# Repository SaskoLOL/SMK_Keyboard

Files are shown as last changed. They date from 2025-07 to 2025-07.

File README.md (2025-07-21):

# SMK_Keyboard
This is a cool 119 key mechanical keyboard. It has 9 macro keys, 4 on top and 5 on the left. (Total time spent: 40h)

#CAD
I modeled everything in fusion 360



This is the full case



It consist of 2 parts:



PCB
The schmetick consists of 119 switches and diodes and uses a rasbarry pi pico (orpheus pico)





The PCB consists only of 2 layers:



UPDATED PICTURE (because I had the thing mirrored and it looked like the screw holes would go trough the pcb and top case)



UPDATE: made the usb space look alot better:



Firmware:
The firmware was made in VS code with Pyhton

BOM:

119 cherry mx switches cost: 52.80€ Required: Yes Link: https://www.reichelt.at/at/de/shop/produkt/cherry_mx_blue_-_tastenmodul_-_fixierzapfen-369269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 

One orpheus pico: 10€ Required: No

M3x16mm screws (6x): 3€: Required: No

119 blank keycaps: 29,90 €: Required: Yes Link:https://www.caseking.de/ducky-blank-white-pbt-set-mda-profile-133-keycaps-ansi-us-layout-ansi-us-layout/GAKC-530.html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 ALIEXPRESS LINK (updated): https://de.aliexpress.com/i/1005008530984427.html?gatewayAdapt=glo2deu Cost:21,07$

3d printing Filament: 20€ Required Yes

Pcb: / Required: Yes
Total cost: 130$

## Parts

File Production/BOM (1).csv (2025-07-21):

Part | Amount | Cost | Link
Neodymium Magnet | 5x2mm | 7 | 7€ | https://amzn.eu/d/3slAySB
Rubber Pad | 10mm | 2 | 4€ | https://amzn.eu/d/7RgwESr
M2.5x10 screw | 7 | 11€ | https://amzn.eu/d/3ODUxXx
Cherry MX switches | 92 | 75€ | https://shop.cherry.de/mx-rgb-black-switch-kit.html
Keycaps | 92 | 25€ | https://amzn.eu/d/aOeOemJ
PCB | 1 | 50€ | jlcpcb.com
RPI Pico | 1 | 17€ | https://amzn.eu/d/3SUL29R
Filament/3d printed case | 1 | 24€ | https://amzn.eu/d/eSc6kCR

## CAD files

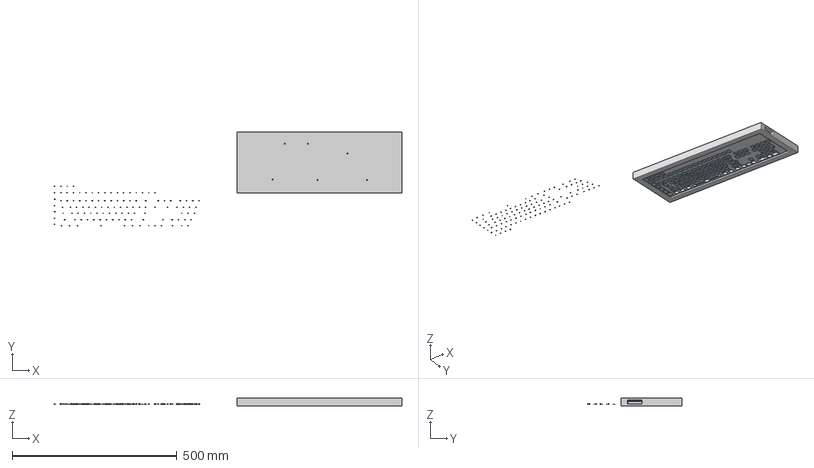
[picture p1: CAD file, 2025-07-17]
Production/wholeKeyboard (1).step
1056.0 x 286.5 x 23.0 mm
Case1
D_SOD-123 x 114
modern-keyboard-template_PCB
f97630a2094c01f0b01be9395de512cac0e4625c_switch

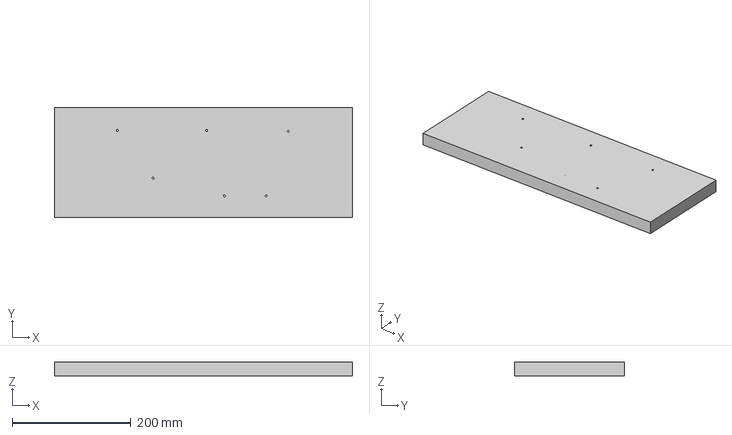
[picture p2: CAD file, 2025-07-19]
Production/Case v3 (1).step
501.0 x 185.0 x 23.0 mm

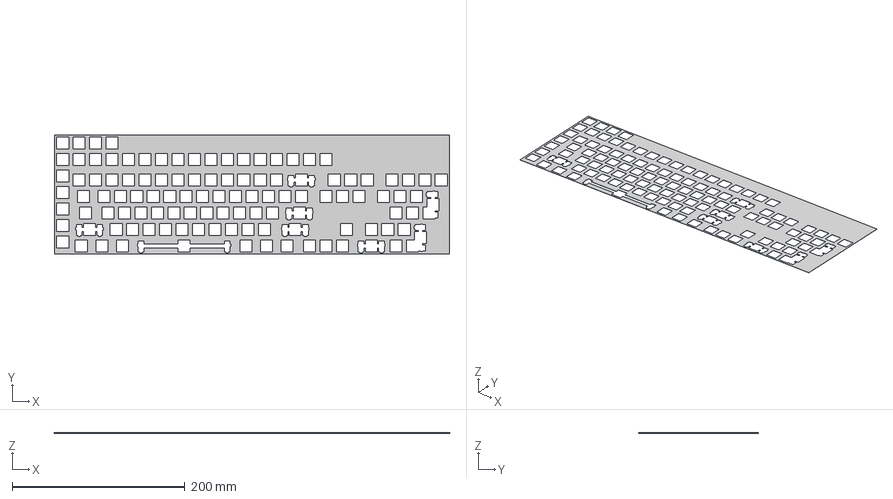
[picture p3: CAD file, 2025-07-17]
Production/topkey (1).step
457.2 x 138.1 x 0.2 mm

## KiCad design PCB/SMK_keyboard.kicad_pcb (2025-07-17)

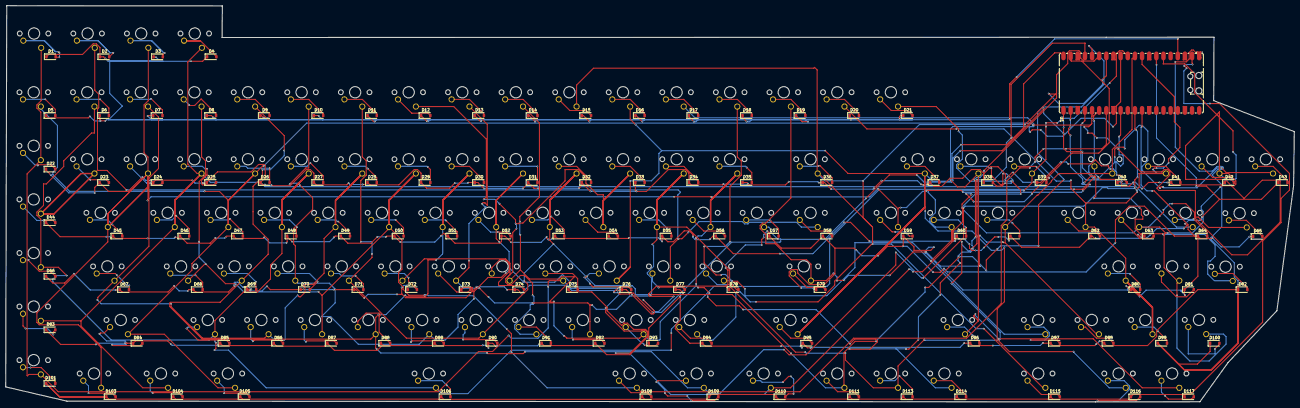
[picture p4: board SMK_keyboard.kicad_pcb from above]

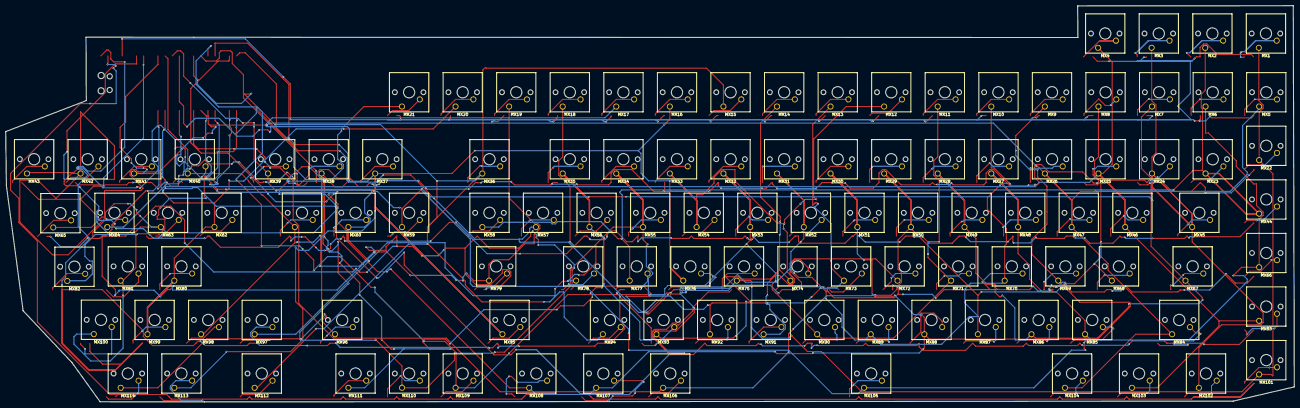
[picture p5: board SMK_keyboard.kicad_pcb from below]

Board: 2 copper layers, 458.2 x 140.9 mm, 229 parts (114 on the bottom side), 141 nets.

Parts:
D1, D2, D3, D4, D5, D6, D7, D8, D9, D10, D11, D12, D13, D14, D15, D16, D17, D18, D19, D20, D21, D22, D23, D24, D25, D26, D27, D28, D29, D30, D31, D32, D33, D34, D35, D36, D37, D38, D39, D40, D41, D42, D43, D44, D45, D46, D47, D48, D49, D50, D51, D52, D53, D54, D55, D56, D57, D58, D59, D60, D61, D62, D63, D64, D65, D66, D67, D68, D69, D70, D71, D72, D73, D74, D75, D76, D77, D78, D79, D80, D81, D82, D83, D84, D85, D86, D87, D88, D89, D90, D91, D92, D93, D94, D95, D96, D97, D98, D99, D100, D101, D103, D104, D105, D106, D108, D109, D110, D111, D113, D114, D115, D116, D117: D; D_SOD-123
MX1, MX2, MX3, MX4, MX5, MX6, MX7, MX8, MX9, MX10, MX11, MX12, MX13, MX14, MX15, MX16, MX17, MX18, MX19, MX20, MX21, MX22, MX23, MX24, MX25, MX26, MX27, MX28, MX29, MX30, MX31, MX32, MX33, MX34, MX35, MX36, MX37, MX38, MX39, MX40, MX41, MX42, MX43, MX44, MX45, MX46, MX47, MX48, MX49, MX50, MX51, MX52, MX53, MX54, MX55, MX56, MX57, MX58, MX59, MX60, MX61, MX62, MX63, MX64, MX65, MX66, MX67, MX68, MX69, MX70, MX71, MX72, MX73, MX74, MX75, MX76, MX77, MX78, MX79, MX80, MX81, MX82, MX83, MX84, MX85, MX86, MX87, MX88, MX89, MX90, MX91, MX92, MX93, MX94, MX95, MX96, MX97, MX98, MX99, MX100, MX101, MX102, MX103, MX104, MX105, MX106, MX107, MX108, MX109, MX110, MX111, MX112, MX113, MX114: MX_SW_HS; SW_Cherry_MX_1.00u_PCB
U1: Pico; RaspberryPi_Pico_Common_SMD

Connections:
unnamed: D1.2 (A), MX1.2
unnamed: D2.2 (A), MX2.2
unnamed: D3.2 (A), MX3.2
unnamed: D4.2 (A), MX4.2
unnamed: D5.2 (A), MX5.2
unnamed: D6.2 (A), MX6.2
unnamed: D7.2 (A), MX7.2
unnamed: D8.2 (A), MX8.2
unnamed: D9.2 (A), MX9.2
unnamed: D10.2 (A), MX10.2
unnamed: D11.2 (A), MX11.2
unnamed: D12.2 (A), MX12.2
unnamed: D13.2 (A), MX13.2
unnamed: D14.2 (A), MX14.2
unnamed: D15.2 (A), MX15.2
unnamed: D16.2 (A), MX16.2
unnamed: D17.2 (A), MX17.2
unnamed: D18.2 (A), MX18.2
unnamed: D19.2 (A), MX19.2
unnamed: D20.2 (A), MX20.2
unnamed: D21.2 (A), MX21.2
unnamed: D22.2 (A), MX22.2
unnamed: D23.2 (A), MX23.2
unnamed: D24.2 (A), MX24.2
unnamed: D25.2 (A), MX25.2
unnamed: D26.2 (A), MX26.2
unnamed: D27.2 (A), MX27.2
unnamed: D28.2 (A), MX28.2
unnamed: D29.2 (A), MX29.2
unnamed: D30.2 (A), MX30.2
unnamed: D31.2 (A), MX31.2
unnamed: D32.2 (A), MX32.2
unnamed: D33.2 (A), MX33.2
unnamed: D34.2 (A), MX34.2
unnamed: D35.2 (A), MX35.2
unnamed: D36.2 (A), MX36.2
unnamed: D37.2 (A), MX37.2
unnamed: D38.2 (A), MX38.2
unnamed: D39.2 (A), MX39.2
unnamed: D40.2 (A), MX40.2
unnamed: D41.2 (A), MX41.2
unnamed: D42.2 (A), MX42.2
unnamed: D43.2 (A), MX43.2
unnamed: D44.2 (A), MX44.2
unnamed: D45.2 (A), MX45.2
unnamed: D46.2 (A), MX46.2
unnamed: D47.2 (A), MX47.2
unnamed: D48.2 (A), MX48.2
unnamed: D49.2 (A), MX49.2
unnamed: D50.2 (A), MX50.2
unnamed: D51.2 (A), MX51.2
unnamed: D52.2 (A), MX52.2
unnamed: D53.2 (A), MX53.2
unnamed: D54.2 (A), MX54.2
unnamed: D55.2 (A), MX55.2
unnamed: D56.2 (A), MX56.2
unnamed: D57.2 (A), MX57.2
unnamed: D58.2 (A), MX58.2
unnamed: D59.2 (A), MX59.2
unnamed: D60.2 (A), MX60.2
unnamed: D61.2 (A), MX61.2
unnamed: D62.2 (A), MX62.2
unnamed: D63.2 (A), MX63.2
unnamed: D64.2 (A), MX64.2
unnamed: D65.2 (A), MX65.2
unnamed: D66.2 (A), MX66.2
unnamed: D67.2 (A), MX67.2
unnamed: D68.2 (A), MX68.2
unnamed: D69.2 (A), MX69.2
unnamed: D70.2 (A), MX70.2
unnamed: D71.2 (A), MX71.2
unnamed: D72.2 (A), MX72.2
unnamed: D73.2 (A), MX73.2
unnamed: D74.2 (A), MX74.2
unnamed: D75.2 (A), MX75.2
unnamed: D76.2 (A), MX76.2
unnamed: D77.2 (A), MX77.2
unnamed: D78.2 (A), MX78.2
unnamed: D79.2 (A), MX79.2
unnamed: D80.2 (A), MX80.2
unnamed: D81.2 (A), MX81.2
unnamed: D82.2 (A), MX82.2
unnamed: D83.2 (A), MX83.2
unnamed: D84.2 (A), MX84.2
unnamed: D85.2 (A), MX85.2
unnamed: D86.2 (A), MX86.2
unnamed: D87.2 (A), MX87.2
unnamed: D88.2 (A), MX88.2
unnamed: D89.2 (A), MX89.2
unnamed: D90.2 (A), MX90.2
unnamed: D91.2 (A), MX91.2
unnamed: D92.2 (A), MX92.2
unnamed: D93.2 (A), MX93.2
unnamed: D94.2 (A), MX94.2
unnamed: D95.2 (A), MX95.2
unnamed: D96.2 (A), MX96.2
unnamed: D97.2 (A), MX97.2
unnamed: D98.2 (A), MX98.2
unnamed: D99.2 (A), MX99.2
unnamed: D100.2 (A), MX100.2
unnamed: D101.2 (A), MX101.2
unnamed: D103.2 (A), MX102.2
unnamed: D104.2 (A), MX103.2
unnamed: D105.2 (A), MX104.2
unnamed: D106.2 (A), MX105.2
unnamed: D108.2 (A), MX106.2
unnamed: D109.2 (A), MX107.2
unnamed: D110.2 (A), MX108.2
unnamed: D111.2 (A), MX109.2
unnamed: D113.2 (A), MX110.2
unnamed: D114.2 (A), MX111.2
unnamed: D115.2 (A), MX112.2
unnamed: D116.2 (A), MX113.2
unnamed: D117.2 (A), MX114.2
unnamed: MX2.1, MX23.1, MX44.1, MX58.1, MX77.1
unnamed: MX12.1, MX33.1, MX54.1, MX72.1, MX91.1
unnamed: MX7.1, MX28.1, MX49.1, MX67.1, MX86.1
Row1: D75.1 (K), D77.1 (K), D82.1 (K), D83.1 (K), D84.1 (K), D85.1 (K), D86.1 (K), D87.1 (K), D88.1 (K), D89.1 (K), D90.1 (K), D91.1 (K), D92.1 (K), D93.1 (K), D94.1 (K), D95.1 (K), D96.1 (K), D97.1 (K), D98.1 (K), D99.1 (K), D100.1 (K), U1.1 (GPIO0)
Row2: D101.1 (K), D103.1 (K), D104.1 (K), D105.1 (K), D106.1 (K), D108.1 (K), D109.1 (K), D110.1 (K), D111.1 (K), D113.1 (K), D114.1 (K), D115.1 (K), D116.1 (K), D117.1 (K), U1.2 (GPIO1)
Row3: D1.1 (K), D2.1 (K), D3.1 (K), D4.1 (K), D5.1 (K), D6.1 (K), D7.1 (K), D8.1 (K), D9.1 (K), D10.1 (K), D11.1 (K), D12.1 (K), D13.1 (K), D14.1 (K), D15.1 (K), D16.1 (K), D17.1 (K), D18.1 (K), D19.1 (K), D20.1 (K), D21.1 (K), U1.4 (GPIO2)
Row4: D22.1 (K), D23.1 (K), D24.1 (K), D25.1 (K), D26.1 (K), D27.1 (K), D28.1 (K), D29.1 (K), D30.1 (K), D31.1 (K), D32.1 (K), D33.1 (K), D34.1 (K), D35.1 (K), D36.1 (K), D37.1 (K), D38.1 (K), D39.1 (K), D40.1 (K), D41.1 (K), D42.1 (K), U1.29 (GPIO22)
Row5: D43.1 (K), D44.1 (K), D45.1 (K), D46.1 (K), D47.1 (K), D48.1 (K), D49.1 (K), D50.1 (K), D51.1 (K), D52.1 (K), D53.1 (K), D54.1 (K), D55.1 (K), D56.1 (K), D60.1 (K), D61.1 (K), D62.1 (K), D63.1 (K), U1.7 (GPIO5)
Row6: D57.1 (K), D58.1 (K), D59.1 (K), D64.1 (K), D65.1 (K), D66.1 (K), D67.1 (K), D68.1 (K), D69.1 (K), D70.1 (K), D71.1 (K), D72.1 (K), D73.1 (K), D74.1 (K), D76.1 (K), D78.1 (K), D79.1 (K), D80.1 (K), D81.1 (K), U1.32 (GPIO27_ADC1)
col0: MX1.1, MX22.1, MX43.1, MX57.1, MX75.1, MX101.1, U1.21 (GPIO16)
col1: MX3.1, MX24.1, MX45.1, MX59.1, MX82.1, MX102.1, U1.22 (GPIO17)
col2: MX4.1, MX25.1, MX46.1, MX64.1, MX83.1, MX103.1, U1.24 (GPIO18)
col3: MX5.1, MX26.1, MX47.1, MX65.1, MX84.1, MX104.1, U1.25 (GPIO19)
col4: MX6.1, MX27.1, MX48.1, MX66.1, MX85.1, MX105.1, U1.26 (GPIO20)
col5: MX8.1, MX29.1, MX50.1, MX68.1, MX87.1, MX106.1, U1.27 (GPIO21)
col6: MX9.1, MX30.1, MX51.1, MX69.1, MX88.1, MX107.1, U1.31 (GPIO26_ADC0)
col7: MX10.1, MX31.1, MX52.1, MX70.1, MX89.1, MX108.1, U1.19 (GPIO14)
col8: MX11.1, MX32.1, MX53.1, MX71.1, MX90.1, MX109.1, U1.16 (GPIO12)
col9: MX13.1, MX34.1, MX55.1, MX73.1, MX92.1, MX110.1, U1.17 (GPIO13)
col10: MX14.1, MX35.1, MX56.1, MX74.1, MX93.1, MX111.1, U1.15 (GPIO11)
col11: MX15.1, MX36.1, MX94.1, MX112.1, U1.14 (GPIO10)
col12: MX16.1, MX37.1, MX76.1, MX95.1, MX113.1, U1.20 (GPIO15)
col13: MX17.1, MX38.1, MX96.1, MX114.1, U1.12 (GPIO9)
col14: MX18.1, MX39.1, MX60.1, MX78.1, MX97.1, U1.11 (GPIO8)
col15: MX19.1, MX40.1, MX61.1, MX79.1, MX98.1, U1.10 (GPIO7)
col16: MX20.1, MX41.1, MX62.1, MX80.1, MX99.1, U1.9 (GPIO6)
col17: MX21.1, MX42.1, MX63.1, MX81.1, MX100.1, U1.6 (GPIO4)

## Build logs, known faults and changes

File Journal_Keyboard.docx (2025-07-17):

Journel by Alexander Kulka for a mechanical Keyboard:

First Session, June 28

So I designed the schematic with the switches diodes and sorted them by rows and collums

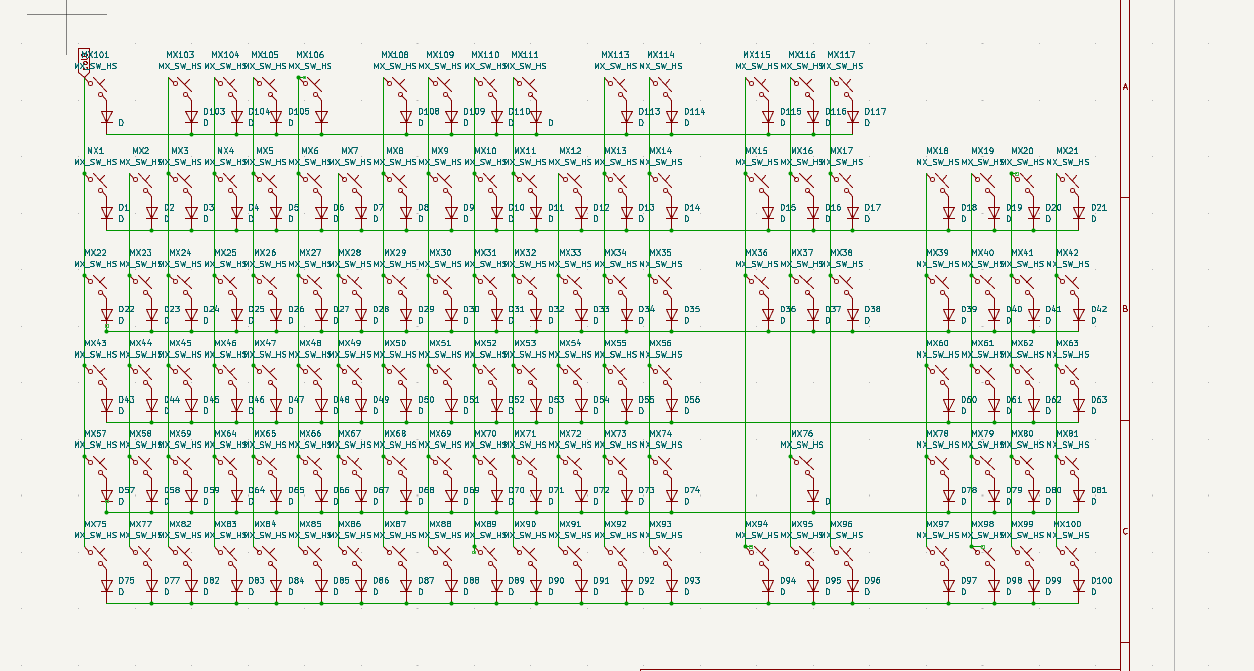
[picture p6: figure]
Obrázok, na ktorom je text, diagram, číslo, písmo Obsah vygenerovaný pomocou AI môže byť nesprávny.

I designed this with the help of a tutorial where he build a keyboard from scratch, in this session I also made the keyboard layout in keyboard layout edititor:

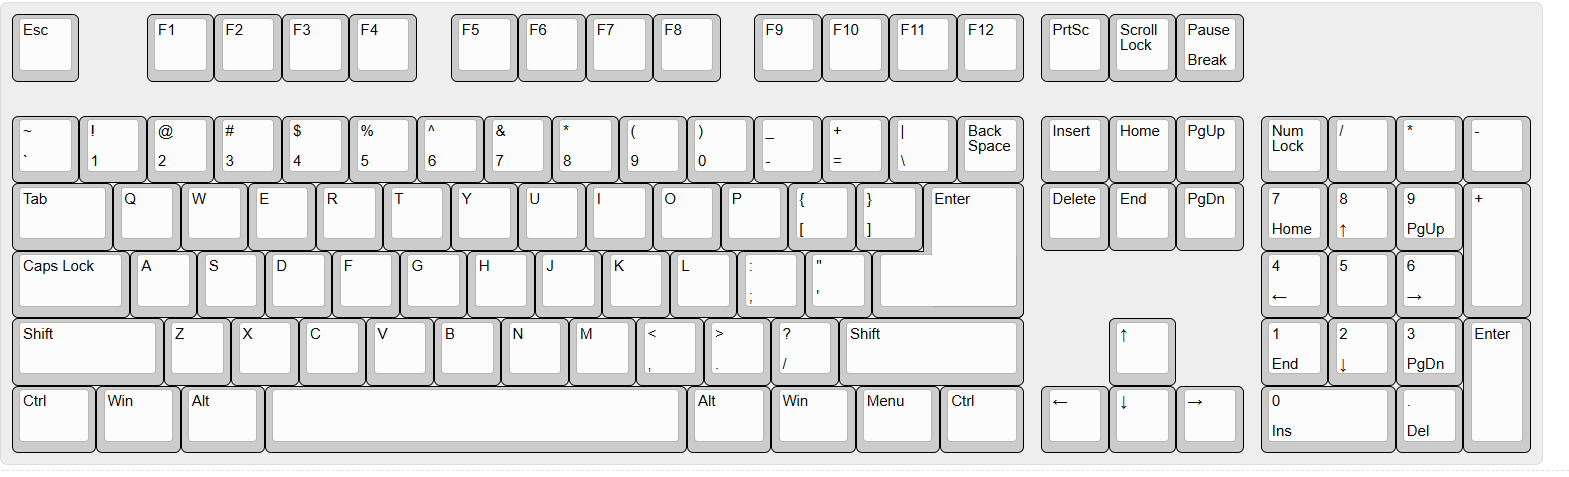
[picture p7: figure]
Obrázok, na ktorom je klávesnica Obsah vygenerovaný pomocou AI môže byť nesprávny.

This is the raw code:

["Esc",{x:1},"F1","F2","F3","F4",{x:0.5},"F5","F6","F7","F8",{x:0.5},"F9","F10","F11","F12",{x:0.25},"PrtSc","Scroll Lock","Pause\nBreak"],

[{y:0.5},"~\n`","!\n1","@\n2","#\n3","$\n4","%\n5","^\n6","&\n7","*\n8","(\n9",")\n0","_\n-","+\n=","|\n\\","Back Space",{x:0.25},"Insert","Home","PgUp",{x:0.25},"Num Lock","/","*","-"],

[{w:1.5},"Tab","Q","W","E","R","T","Y","U","I","O","P","{\n[","}\n]",{w:1.5,h:2,w2:2.25,h2:1,x2:-0.75,y2:1},"Enter",{x:0.25},"Delete","End","PgDn",{x:0.25},"7\nHome","8\n↑","9\nPgUp",{h:2},"+"],

[{w:1.75},"Caps Lock","A","S","D","F","G","H","J","K","L",":\n;","\"\n'",{x:5.75},"4\n←","5","6\n→"],

[{w:2.25},"Shift","Z","X","C","V","B","N","M","<\n,",">\n.","?\n/",{w:2.75},"Shift",{x:1.25},"↑",{x:1.25},"1\nEnd","2\n↓","3\nPgDn",{h:2},"Enter"],

[{w:1.25},"Ctrl",{w:1.25},"Win",{w:1.25},"Alt",{a:7,w:6.25},"",{a:4,w:1.25},"Alt",{w:1.25},"Win",{w:1.25},"Menu",{w:1.25},"Ctrl",{x:0.25},"←","↓","→",{x:0.25,w:2},"0\nIns",".\nDel"]

Session time: 7 hours.

June 29th:

I started working on the pcb:

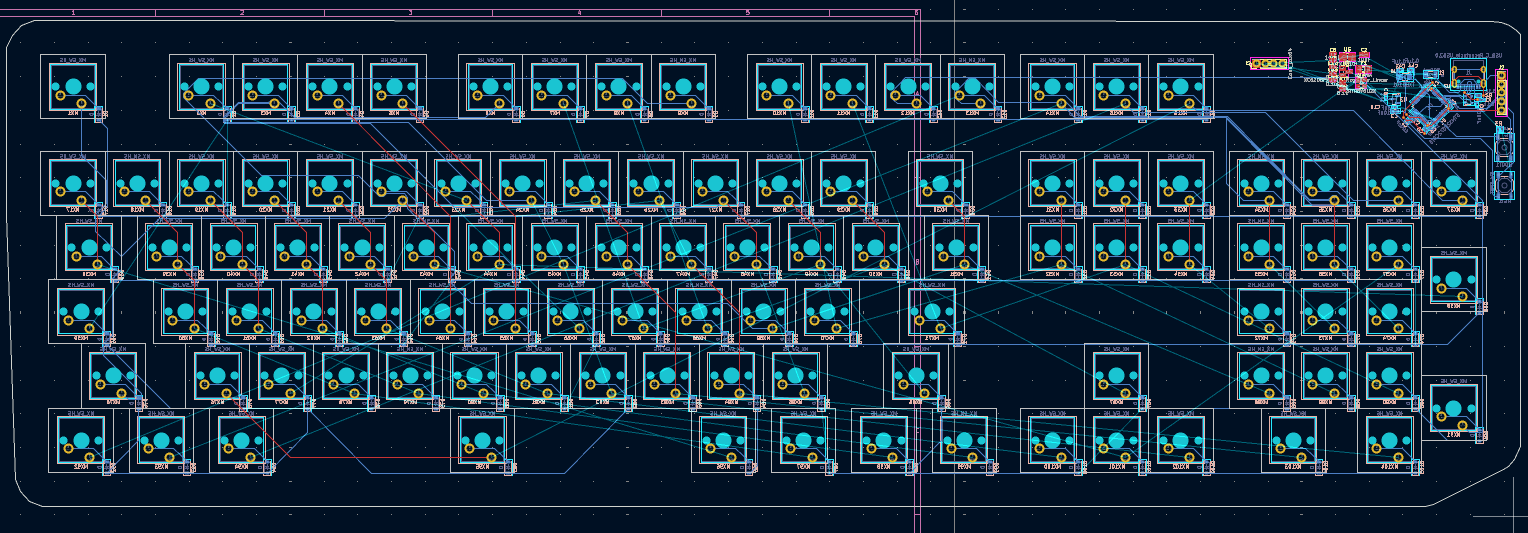
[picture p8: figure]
Obrázok, na ktorom je snímka obrazovky, elektronika, okruh, elektrinžinierstvo Obsah vygenerovaný pomocou AI môže byť nesprávny.

Which I set up with the build in keyboard layout tool in Kicad. I also started wiring it but the lag was way too much to even start with it, it took me 3 hours only to do a few cables so I decided to try use freerouter tool, I worked on this for like 5 hours and it just wouldn’t work, I really tried everything. I give ☹… I actually don’t but this is enough for today.

Time spent: 8 fric*ing hours like what

July 2nd: So again tried freerouter… BIG mistake I hate it so much why does it even exist… So apart from that I actually started wiring:

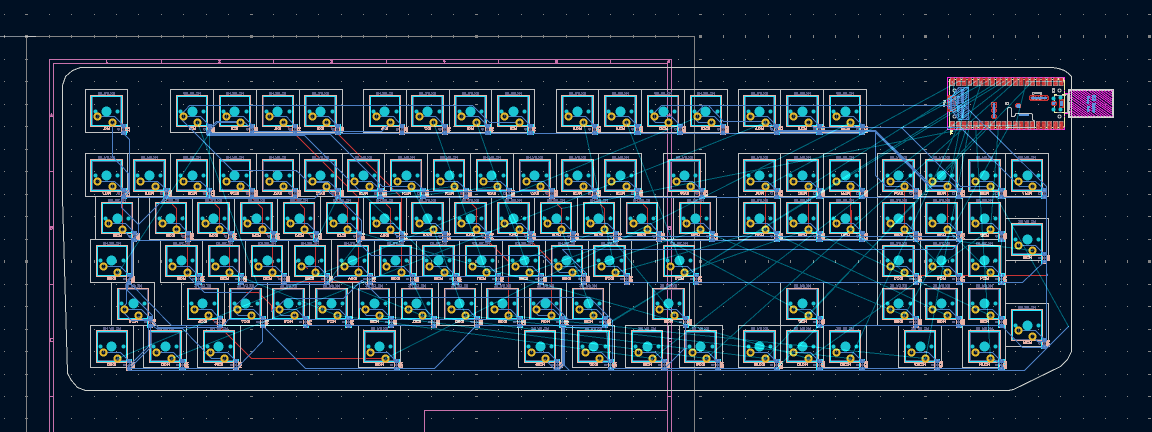
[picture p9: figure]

I changed to a pi pico (orpheus pico) because I realized I copied the setup from that one tutorial and didnt want to do that, after wiring like half of it I realized something... hard to see on the pic but I wondered, why do the Gpio pins on the pico need to be connected?? Well... as I looked at my schematic I realized my dumb*ss dindnt connect the rows, so I fixed that. Here is the new schematic:

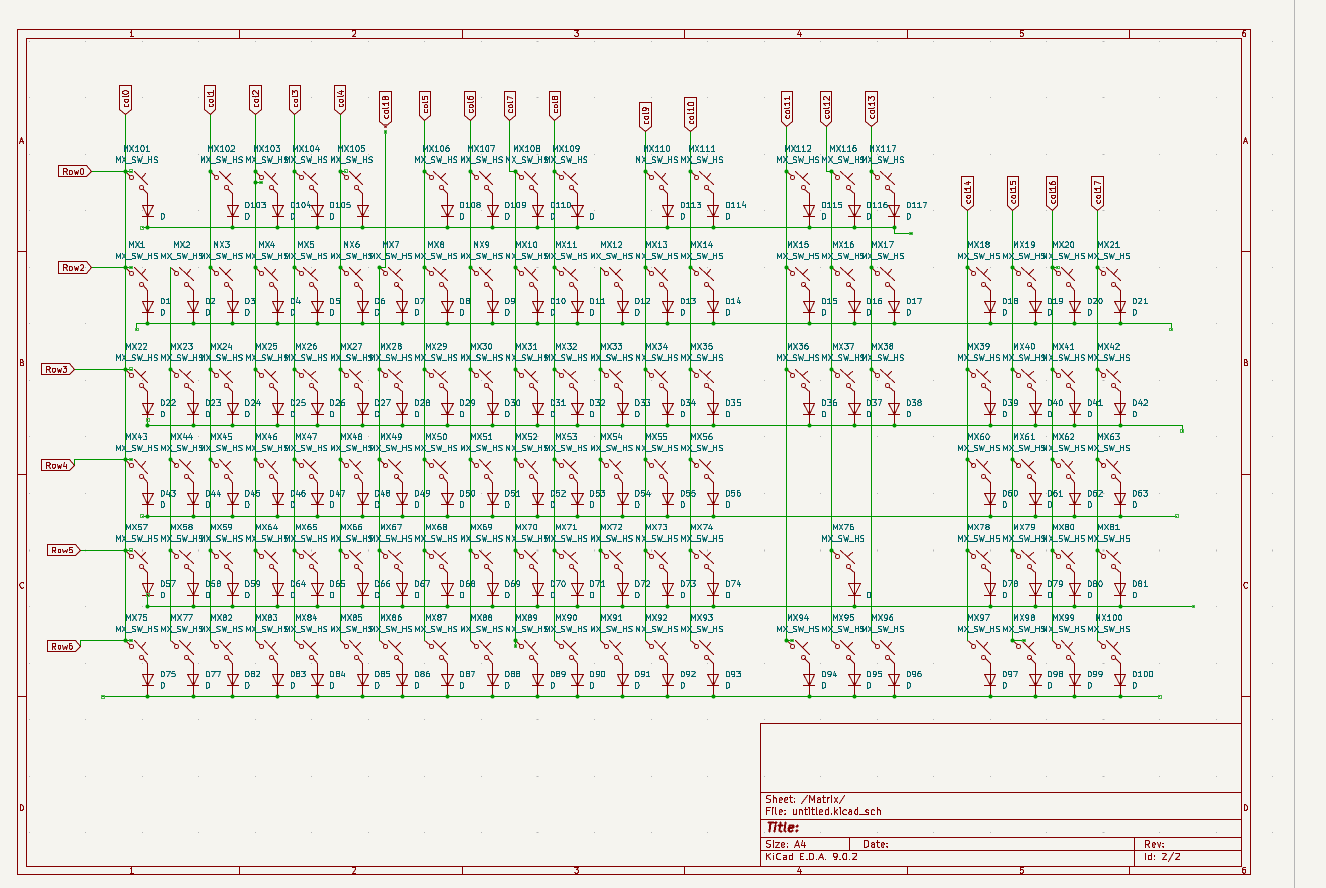
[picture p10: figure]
Obrázok, na ktorom je text, číslo, diagram, písmo Obsah vygenerovaný pomocou AI môže byť nesprávny.

I have to do everything again… :§

Time spent: 6 hours

July 16th:

So I finally finished wiring the PCB after many many problems (they are all my fault lol)

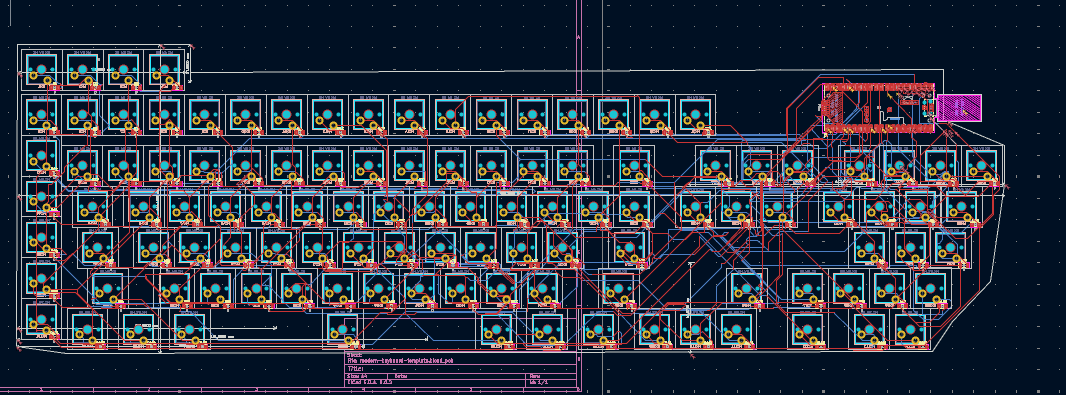
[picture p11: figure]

The wiring is so messy but everything works, I had to fix like 600 errors…

Also, as you see in the pcb I changed the keyboard layout into a custum one which uses all my keys as the one before didn’t do that (why is chatgpt so dumb he couldn’t change like 2 lines of code like what).

Time spent: 12 hours

July 16-17th: Hopefully last session (prob not as I suck at Fusion 360 like help)

SO I pretty much made the case after much suffering…. I had problems figuring out how big the case should be and all of the dimensions, but I made it work:

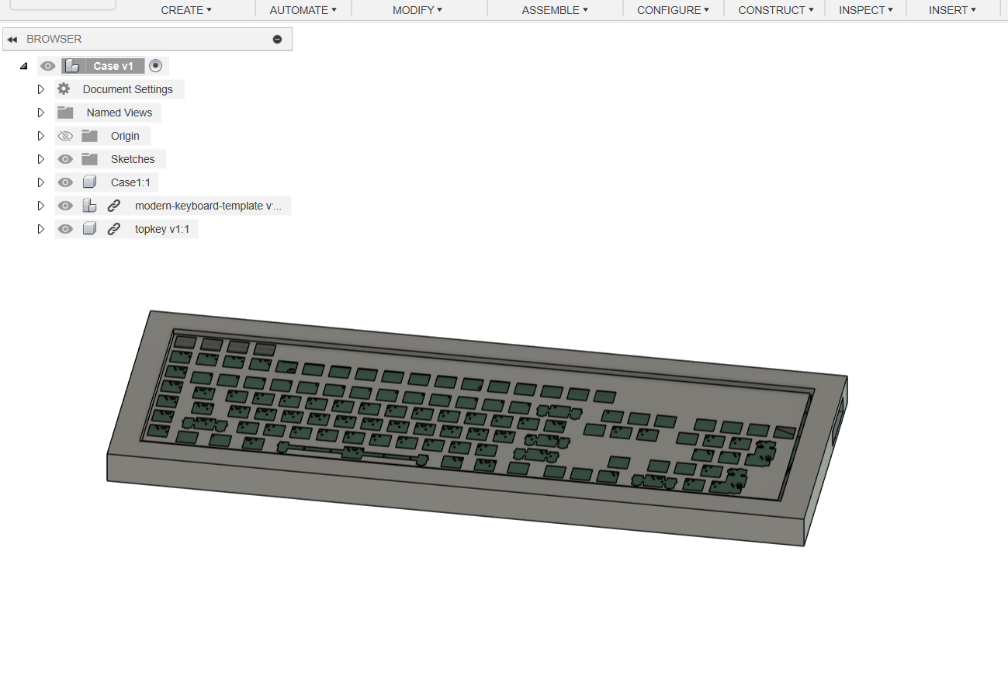
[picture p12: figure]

I got the top from a CAD generator

Time spent: 5 hours

July 17th:

Made Firmware for the pico and keyboard

Time spent: 1 hour (I don’t know what to show here lol)

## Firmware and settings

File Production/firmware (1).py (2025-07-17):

from kmk.kmk_keyboard import KMKKeyboard
from kmk.keys import KC
from kmk.scanners import DiodeOrientation
import board

keyboard = KMKKeyboard()

# Define column and row pins for 17x7 matrix
keyboard.col_pins = (
    board.GP0, board.GP1, board.GP2, board.GP3, board.GP4, board.GP5,
    board.GP6, board.GP7, board.GP8, board.GP9, board.GP10, board.GP11,
    board.GP12, board.GP13, board.GP14, board.GP15, board.GP16
)

keyboard.row_pins = (
    board.GP17, board.GP18, board.GP19, board.GP20,
    board.GP21, board.GP22, board.GP26  # 7 rows
)

keyboard.diode_orientation = DiodeOrientation.COL2ROW

# 119-key keymap layout (rows * cols order)
keyboard.keymap = [
    [
        # Row 0 (Top macro row)
        KC.M6, KC.M7, KC.M8, KC.M9, KC.NO, KC.NO, KC.NO, KC.NO, KC.NO, KC.NO, KC.NO, KC.NO, KC.NO, KC.NO, KC.NO, KC.NO, KC.NO,

        # Row 1 (Macro column, starting from second physical row)
        KC.M1, KC.NO, KC.NO, KC.NO, KC.NO, KC.NO, KC.NO, KC.NO, KC.NO, KC.NO, KC.NO, KC.NO, KC.NO, KC.NO, KC.NO, KC.NO, KC.NO,

        # Row 2 (Main F-row and top numbers)
        KC.M2, KC.ESC, KC.F1, KC.F2, KC.F3, KC.F4, KC.F5, KC.F6, KC.F7, KC.F8, KC.F9, KC.F10, KC.F11, KC.F12, KC.PSCR, KC.SLCK, KC.PAUS,

        # Row 3
        KC.M3, KC.GRAVE, KC._1, KC._2, KC._3, KC._4, KC._5, KC._6, KC._7, KC._8, KC._9, KC._0, KC.MINS, KC.EQL, KC.BSPC, KC.INS, KC.HOME,

        # Row 4
        KC.M4, KC.TAB, KC.Q, KC.W, KC.E, KC.R, KC.T, KC.Y, KC.U, KC.I, KC.O, KC.P, KC.LBRC, KC.RBRC, KC.BSLS, KC.DEL, KC.END,

        # Row 5
        KC.M5, KC.CAPS, KC.A, KC.S, KC.D, KC.F, KC.G, KC.H, KC.J, KC.K, KC.L, KC.SCLN, KC.QUOT, KC.ENT, KC.NO, KC.NO, KC.NO,

        # Row 6
        KC.LSFT, KC.Z, KC.X, KC.C, KC.V, KC.B, KC.N, KC.M, KC.COMM, KC.DOT, KC.SLSH, KC.RSFT, KC.UP, KC.NO, KC.NO, KC.NO, KC.NO
    ]
]
keyboard.debug_enabled = True

if __name__ == '__main__':
    keyboard.go()
